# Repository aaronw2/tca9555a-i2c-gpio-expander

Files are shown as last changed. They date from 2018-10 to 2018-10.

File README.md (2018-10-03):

TCA9555A i2c GPIO expander board

I am doing an ESP32 Wrover based design and I need additional GPIO pins to
monitor 10 hall effect sensors. I want to generate an interrupt whenever one
of them is triggered. This board is designed so that I can plug my existing
ribbon cable directly into J2 (with the pins installed on the back of the
board) with J3 providing the rest of the pins.

J1 provides power, ground, interrupt, i2c SDA and i2c SCL signals.  All of
the signals are duplicated so that the boards can be chained together by
alternating 5-pin male and female header.

The TCA9555A is capable of 400KHz i2c.
It can generate an interrupt whenever one of the unmasked pins changes state.

The switches are as follows:

1: Enable the interrupt pull-up.  This should only be on for the last
   board in the i2c chain.
2: Enable SDA pull-up.  This should only be on for the last board in the
   i2c chain.
3: Enable SCL pull-up.  This should only be on for the last board in the
   i2c chain.
4: Sets the A0 bit 1 when on, 0 when off.
5: Sets the A1 bit 1 when on, 0 when off.
6: Sets the A2 bit 1 when on, 0 when off.

A datasheet on the GPIO expander can be found here:
http://www.ti.com/lit/ds/symlink/tca9555.pdf

The base i2c address is 0x20 and can be adjusted via the A0-A2 switches to
use addresses 0x20 through 0x27.

Please use insulating washers between any screws and stand-offs when
mounting this board to prevent shorts between power and ground.

While the board is listed as supporting 3V.  It is capable of running
anywhere between 1.65 and 5.5v.  All GPIO pins are 5v tolerant.

Please direct any questions or comments to Aaron Williams <aaron.w2@gmail.com>

Copyright (C) 2018 by Aaron Williams

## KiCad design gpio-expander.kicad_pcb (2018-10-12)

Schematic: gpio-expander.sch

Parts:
C1: 1uF; C_0603_1608Metric
C2, C3, C4: 10uF; C_0805_2012Metric
FID1, FID4: FIDUCIAL_1MM; Fiducial_1mm_Dia_2.54mm_Outer_CopperTop
FID2, FID3: FIDUCIAL_1MM; Fiducial_1mm_Dia_2.54mm_Outer_CopperBottom
J1: Conn_01x10; Pin_Header_Angled_1x10_Pitch2.54mm
J2: Conn_02x07_Odd_Even; Pin_Header_Angled_2x07_Pitch2.54mm
J3: Conn_02x04_Odd_Even; Pin_Header_Angled_2x04_Pitch2.54mm
MH1, MH2: MountingHole; MountingHole_2.5mm
RN1: R_Pack02; R_Array_Concave_2x0603
RN2: 10k; R_Array_Convex_4x0603
SW1: SW_DIP_x06; SW_DIP_SPSTx06_Slide_GrayHill_97C06_W4.5mm_P1.27mm
U1: TCA9555DBT; TSSOP-24_4.4x7.8mm_P0.65mm

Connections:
+3V3: C1.1, C2.1, C3.1, C4.1, J1.5, J1.10, J2.1, J3.1, SW1.1, SW1.2, SW1.3, SW1.4, SW1.5, SW1.6, U1.24 (VCC)
/A0: RN2.3, SW1.9, U1.21 (A0)
/A1: RN2.2, SW1.8, U1.2 (A1)
/A2: RN2.1, SW1.7, U1.3 (A2)
/P00: J2.3, U1.4 (P00)
/P01: J2.4, U1.5 (P01)
/P02: J2.5, U1.6 (P02)
/P03: J2.6, U1.7 (P03)
/P04: J2.7, U1.8 (P04)
/P05: J2.8, U1.9 (P05)
/P06: J2.9, U1.10 (P06)
/P07: J2.10, U1.11 (P07)
/P10: J2.11, U1.13 (P10)
/P11: J2.12, U1.14 (P11)
/P12: J3.3, U1.15 (P12)
/P13: J3.4, U1.16 (P13)
/P14: J3.5, U1.17 (P14)
/P15: J3.6, U1.18 (P15)
/P16: J3.7, U1.19 (P16)
/P17: J3.8, U1.20 (P17)
/SCL: J1.3, J1.8, RN2.5, U1.22 (SCL)
/SCL_PU: RN2.4, SW1.10
/SDA: J1.4, J1.9, RN1.2, U1.23 (SDA)
/SDA_PU: RN1.3, SW1.11
/~INT: J1.2, J1.7, RN1.1, U1.1 (~INT)
/~INT_PU: RN1.4, SW1.12
GND: C1.2, C2.2, C3.2, C4.2, J1.1, J1.6, J2.2, J2.13, J2.14, J3.2, RN2.6, RN2.7, RN2.8, U1.12 (GND)

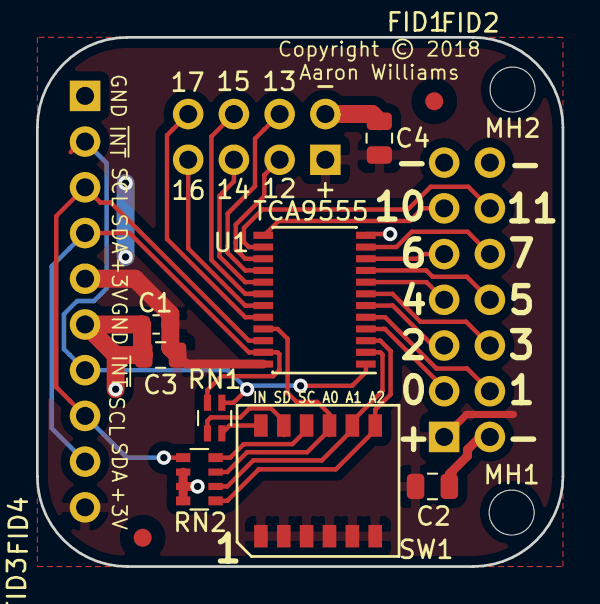
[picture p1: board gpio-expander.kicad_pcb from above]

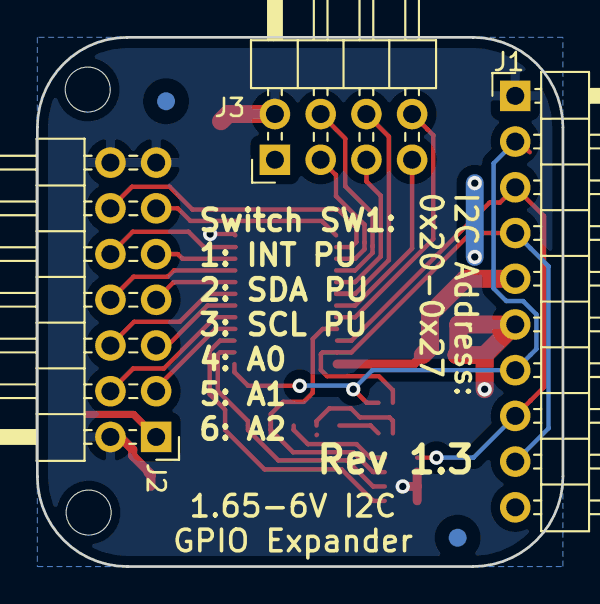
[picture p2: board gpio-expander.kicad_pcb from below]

Board: 2 copper layers, 29.2 x 29.4 mm, 17 parts (3 on the bottom side), 27 nets.

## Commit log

2018-09-19 Initial checkin
    [gpio-expander.kicad_pcb, gpio-expander.sch]
2018-09-19 Added gerber files
    [gpio-expander-B.Cu.gbr, gpio-expander-B.Mask.gbr, gpio-expander-B.Paste.gbr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]
2018-10-02 Rev 1.2
    [gpio-expander.kicad_pcb, gpio-expander.sch]
2018-10-03 - Added a dip switch for setting the address and termination - Added mounting holes - Changed J1 to a 10-pin connector with all pins duplicated for stacking - Minor cleanup - Updated README
    [gpio-expander-B.Cu.gbr, gpio-expander-B.Mask.gbr, gpio-expander-B.Paste.gbr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]
2018-10-11 Fixed solder mask clearance.
    [gpio-expander-B.Cu.gbr, gpio-expander-B.Mask.gbr, gpio-expander-B.Paste.gbr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]
2018-10-12 Fixed the footprint to not use a git library.
    [gpio-expander.kicad_pcb, gpio-expander.sch]
2018-10-12 Minor change. Made trace 45 degree instead of 90 degrees.
    [gpio-expander.kicad_pcb]

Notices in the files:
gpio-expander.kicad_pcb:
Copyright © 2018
